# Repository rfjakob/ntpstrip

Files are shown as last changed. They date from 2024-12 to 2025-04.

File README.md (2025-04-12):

# ntpstrip: display internet time and sun hours on a led strip

Inspired by [hometime](https://github.com/veebch/hometime),
and using the
[same hardware](https://github.com/veebch/hometime?tab=readme-ov-file#hardware),
but with much simpler software.

## Hardware

* Raspberry Pi Pico W
* 5V Addressable LED strip: WS2812B Eco, 1m, 144 LEDs
* Printout of [dial.svg](docs/dial.svg) (print at 1:1 scale or it won't fit!)

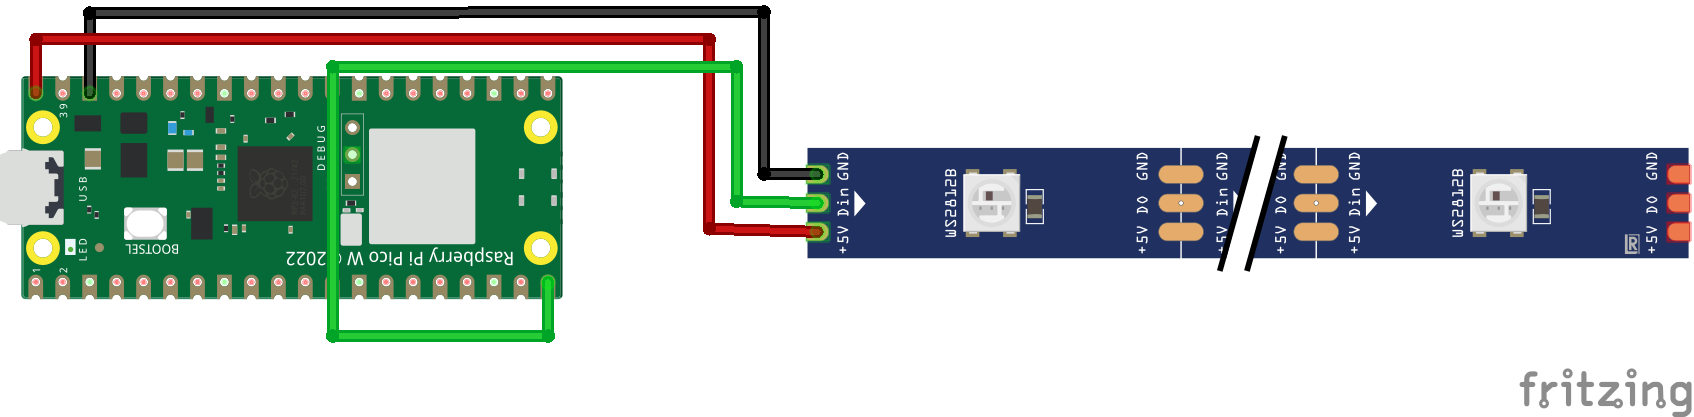
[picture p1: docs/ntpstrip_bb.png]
fritzing schematic


## Finished Product

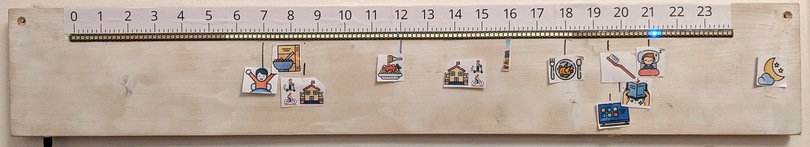
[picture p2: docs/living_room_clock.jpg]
photo of our living room clock


Over the course of the year the yellow pixels will show the actual daylight
hours. Here's how it looks for Vienna, Austria from Jan 1st to Dec 31:

```
______________________________________________==========================X========================_______________________________________________
______________________________________________==========================X=========================______________________________________________
____________________________________________============================X============================___________________________________________
__________________________________________==============================X==============================_________________________________________
_______________________________________=================================X================================_______________________________________
____________________________________====================================X===================================____________________________________
_______________________________________=================================X===========================================____________________________
____________________________________====================================X=============================================__________________________
_________________________________=======================================X===============================================________________________
_______________________________=========================================X=================================================______________________
______________________________==========================================X===================================================____________________
_____________________________===========================================X====================================================___________________
_____________________________===========================================X====================================================___________________
_______________________________=========================================X====================================================___________________
________________________________========================================X==================================================_____________________
__________________________________======================================X================================================_______________________
____________________________________====================================X=============================================__________________________
______________________________________==================================X==========================================_____________________________
________________________________________================================X=======================================________________________________
___________________________________________=============================X====================================___________________________________
_______________________________________=================================X===========================____________________________________________
_________________________________________===============================X=========================______________________________________________
___________________________________________=============================X=======================________________________________________________
_____________________________________________===========================X=======================________________________________________________
______________________________________________==========================X=======================________________________________________________
```

## Comparison with hometime

| | [hometime](https://github.com/veebch/hometime) | **ntpstrip** |
|---|---|---|
| Shows Google Calender events | ✅ | ❌ |
| Time source | Proprietary cloud service: https://timeapi.io  | Standard NTP: pool.ntp.org |
| Timezone + DST support | Proprietary cloud service: https://timeapi.io  | Local calculation using [localPTZtime](https://github.com/bellingeri/localPTZtime) lib |
| Display mode | Progress bar | Single dot |
| Time range | Workday (configurable) | Full 24h (fixed)  |
| Wifi config | Temporary access point + webform | config.py |

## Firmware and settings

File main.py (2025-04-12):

import network
import time
import json
import ntptime
import neopixel
import math
import machine

import localPTZtime
import Suntime

# Local config
import config


class TimeOfDay:
    def __init__(self, year=0, month=0, d=0, h=0, m=0, s=0, utc_offset_h=0):
        self.year = year
        self.month = month
        self.d = d
        self.h = h
        self.m = m
        self.s = s
        # UTC offset in hours. Example: CEST = +2.
        self.utc_offset_h = utc_offset_h


def wifi_pretty_status(status):
    """
    Pretty-print network.WLAN.status()
    """
    well_known = {
        network.STAT_IDLE: "IDLE",
        network.STAT_CONNECTING: "CONNECTING",
        network.STAT_WRONG_PASSWORD: "WRONG_PASSWORD",
        network.STAT_NO_AP_FOUND: "NO_AP_FOUND",
        network.STAT_CONNECT_FAIL: "CONNECT_FAIL",
        network.STAT_GOT_IP: "GOT_IP",
    }

    if status in well_known:
        return f"{status}/{well_known[status]}"

    # Yes, this happens. The docs are incomplete.
    return f"{status}"


def wifi_connect(wlan):
    """
    Connect to wifi using credentials in config.py.
    Waits at most 20 seconds for a connection.
    """

    wlan.active(False)
    wlan.active(True)
    print(f'Connecting to wifi "{config.WIFI_SSID}"...')
    wlan.connect(config.WIFI_SSID, config.WIFI_PASSWORD)
    status_pixel(STATUS_CONNECTING)

    retry = 1
    maxretry = 20

    while retry <= maxretry:
        status = wifi_pretty_status(wlan.status())
        print(f"Waiting for wifi {retry}/{maxretry}, status={status}")

        if wlan.isconnected():
            ip = wlan.ifconfig()[0]
            print(f"Wifi connected, ip={ip}")
            status_pixel(STATUS_HAVE_WIFI)
            return True

        time.sleep(1)
        retry += 1

    return False


def ntp_sync():
    retry = 1
    maxretry = 3

    while retry <= maxretry:
        print(f"NTP sync try {retry}/{maxretry}...")
        try:
            t_before = time.time()
            ntptime.settime()
            offset = t_before - time.time()
            print(f"NTP sync ok, our clock error was {offset:+}s")
            status_pixel(STATUS_HAVE_NTP)
            return True
        except Exception as e:
            print(f"NTP sync failed: {e}")

        time.sleep(1)
        retry += 1

    status_pixel(STATUS_HAVE_WIFI)
    return False


STATUS_CONNECTING = (10, 0, 0)
STATUS_HAVE_WIFI = (0, 10, 0)
STATUS_HAVE_NTP = (0, 0, 0)

status_pixel_value = (0, 0, 0)


def status_pixel(color=None):
    """
    Show boot progress in first pixel
    """
    global status_pixel_value
    status_pixel_value = color

    global np
    np[flip_index(0)] = status_pixel_value
    np.write()


def flip_index(index):
    """
    If config.FLIP is set, flip left and right by reversing
    the led index order.
    """
    if not config.FLIP:
        return index
    return config.PIXELS-index-1

def timeToPixel(now: TimeOfDay) -> int:
    """
    Calculate the pixel index [0...config.PIXELS) corresponding
    to the time.
    """

    fractional_day = now.h / 24 + now.m / 1440 + now.s / 86400
    pixel_index = int(math.floor(config.PIXELS * fractional_day))

    return pixel_index


def render_time(now: TimeOfDay, sunrise: TimeOfDay, sunset: TimeOfDay):
    """
    Show the current time as a single dot on the LED strip
    with sunlight hours in the background.
    """
    global np
    np.fill((0, 0, 0))

    global ascii_art
    for i in range(len(ascii_art)):
        ascii_art[i] = 0x5f # Underscore "_"

    # The fill() overwrote the status pixel. Restore it.
    global status_pixel_value
    np[flip_index(0)] = status_pixel_value

    for i in range(timeToPixel(sunrise), timeToPixel(sunset)):
        np[flip_index(i)] = config.SUN_COLOR
        ascii_art[flip_index(i)] = 0x3d # Equal sign "="

    index_now = flip_index(timeToPixel(now))
    np[index_now] = config.DOTCOLOR
    np.write()

    ascii_art[index_now] = 0x58 # Uppercase X
    print(ascii_art)

    return index_now


def localTimeOfDay(t: float) -> TimeOfDay:
    """
    Convert a `time.time()` timestamp to local time
    """
    out = TimeOfDay()

    (
        out.year,
        out.month,
        out.d,
        out.h,
        out.m,
        out.s,
        _,
        _,
        _,
        utc_offset_seconds,
    ) = localPTZtime._timecalc(t, config.POSIX_TZ_STRING)

    out.utc_offset_h = int(utc_offset_seconds / 3600)

    return out


def main():
    # Onboard LED shows that main.py has started executing
    led = machine.Pin("LED", machine.Pin.OUT)
    led.on()

    wlan = network.WLAN(network.STA_IF)

    print("Initial sync...")
    while True:
        if wifi_connect(wlan):
            pass
        else:
            continue

        if ntp_sync():
            last_ntp_sync = time.time()
            break

    # Don't distract from the time display
    led.off()

    loop_count = 0
    loop_sleep = 10
    last_day = 0

    sunrise = TimeOfDay()
    sunset = TimeOfDay()

    if config.STRESS_TEST:
        loop_sleep = 0

    # Main loop
    while True:
        loop_count += 1

        t = time.time()
        if config.STRESS_TEST:
            t += loop_count * 600

        now = localTimeOfDay(t)

        # Update sunrise/sunset on day change after 4am (wait out DST changes!)
        if last_day != now.d and now.h >= 4:
            sun = Suntime.Sun(config.LAT, config.LON, now.utc_offset_h)
            _, _, _, sunrise.h, sunrise.m = sun.get_sunrise_time(time.localtime(t))
            _, _, _, sunset.h, sunset.m = sun.get_sunset_time(time.localtime(t))
            print(f"Recalculated sunrise={sunrise.h:02}:{sunrise.m:02} sunset={sunset.h:02}:{sunset.m:02} local time")
            last_day = now.d

        index = render_time(now, sunrise, sunset)
        wifi_status = wifi_pretty_status(wlan.status())
        print(
            f"{now.year}-{now.month:02}-{now.d:02} {now.h:02}h{now.m:02}m{now.s:02}s = pixel #{index+1:3} wifi={wifi_status} loop={loop_count} t={t}"
        )

        # NTP resync needed?
        if t < last_ntp_sync + 24 * 3600:
            # No
            time.sleep(loop_sleep)
            continue

        # Yes
        if ntp_sync():
            last_ntp_sync = t
        else:
            # Probably failed due to wifi problems. Try reconnecting.
            wifi_connect(wlan)

# Globals defined here so ascii_year.py can easily call main.render_time()
ascii_art = bytearray(config.PIXELS)
np = neopixel.NeoPixel(machine.Pin(config.GPIOPIN), config.PIXELS)

if __name__ == "__main__":
    main()

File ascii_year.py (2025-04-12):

# Prints 24 lines of the year 2025 sun progression as ascii art

import config
import main
import neopixel
import Suntime
import time

sunrise = main.TimeOfDay()
sunset = main.TimeOfDay()

t = 1735729200 # 2025-01-01 12:00 CET

while True:
    now = main.localTimeOfDay(t)
    now.h = 12
    if now.year > 2025:
        break

    sun = Suntime.Sun(config.LAT, config.LON, now.utc_offset_h)
    _, _, _, sunrise.h, sunrise.m = sun.get_sunrise_time(time.localtime(t))
    _, _, _, sunset.h, sunset.m = sun.get_sunset_time(time.localtime(t))

    main.render_time(now, sunrise, sunset)
    
    # Add 15 days
    t += 15*3600*24

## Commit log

2024-06-23 Enable onboard LED, explain POSIX_TZ_STRING better
2024-06-25 Log loop iteration number and clock error
    [main.py]
2024-06-25 Fix retry count off-by-one
    [main.py]
2024-06-25 config_example.py: fix typo in DOTCOLOR
    This was bluer than indented.
    [config_example.py]
2024-06-27 Turn off on-board led after boot
2024-06-28 Add divergentti's Suntime.py
    MIT licensed.
    Downloaded from:
    https://github.com/divergentti/airquality/blob/b383bb6ddd1ae24bb4458e7c43334c28812187f7/esp32/solarpanelrotator/Suntime.py
    Recommended here (incl. example usage):
    https://forum.micropython.org/viewtopic.php?t=2059#p55205
    Copied below:
    Re: Astral port/alternative
    Post by Divergentti » Sat Feb 20, 2021 1:11 pm
    Perhaps somewhere is better code available for MPY, but I ported Suntime class
    for Micropython. https://github.com/divergentti/airquali ... Suntime.py and this
    seems to be quite ok.
    Compared to Google, sun rise drifts a few minutes, sun set is OK.
    Original: https://github.com/SatAgro/suntime
    Usage:
    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
    [Suntime.py]
2024-07-12 suntime: Add MidnightSunException, PolarNightException
    Instead of just raising SunTimeException, report
    whether we have midnight sun or polar night.
    Implemented in a backwards-compatible way by
    subclassing SunTimeException.
    That catching SunTimeException still works as before
    is verified by extending the tests.
    Fixes https://github.com/SatAgro/suntime/issues/32
    Upstream PR:
    https://github.com/SatAgro/suntime/pull/33/commits/0b59d7b20470f174e2eef5631c2a99d813978820
    [Suntime.py]
2024-07-12 Print date as well
2024-12-01 Add fritzing schematic
    [ntpstrip.fzz]
2024-12-01 print scale warning
2025-04-01 bugfix: make sunrise and sunset follow dst changes
    Up till now, it used the utc offset from startup.
    [main.py]
2025-04-12 Print LED ASCII art
    Example:
    bytearray(b'_____________________________________=====X===========================================================================__________________________')
    bytearray(b'_____________________________________======X==========================================================================__________________________')
    bytearray(b'_____________________________________=======X=========================================================================__________________________')
    bytearray(b'_____________________________________========X========================================================================__________________________')
    bytearray(b'______________________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
2025-04-12 Add FLIP config
    For people who like their time running backwards.
    Or accidentially made the clock upside down (like I did).
    bytearray(b'__________________________======X==========================================================================_____________________________________')
    bytearray(b'__________________________=====X===========================================================================_____________________________________')
    bytearray(b'__________________________====X============================================================================_____________________________________')
    bytearray(b'__________________________===X========================================================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
    [config_example.py, main.py]
